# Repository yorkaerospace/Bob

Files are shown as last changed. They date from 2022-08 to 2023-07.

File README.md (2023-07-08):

# ARCHIVED REPO
Keeping hardware and software in the same repository causes headache on top of headache. To that end, this repo was archived on 2023-07-08 and further development will continue in the following repos:
- [ProtonNumber/Bob-Firmware](https://github.com/ProtonNumber/Bob-Firmware)  
- [ProtonNumber/Bob-Hardware](https://github.com/ProtonNumber/Bob-Hardware)
- [ProtonNumber/Bob-Drivers](https://github.com/ProtonNumber/Bob-Drivers)

# Bob

Simple RP2040 based datalogger.

## Rev 3 Specs:

 - 8MB of flash storage (Winbond W25Q64)
 - Barometer/Altimiter (HopeRF HP203B)
 - 6-Axis IMU (QST QMI8658C)
 - 3-Axis Magnetometer (QST QMC5883L)
 
 See docs folder for datasheets.

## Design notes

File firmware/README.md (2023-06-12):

# Bob Firmware
Rewrite of Bob's firmware, using platformIO. The main goal here is to make something simpler, which will hopefully be more reliable and easier to extend.

## Known issues with the old firmware:
 - Overuse of single use function calls.
 - Firmware was split into too many modules, which, combined with the single use functions, made it hard to keep track of program flow.
 - Design was generally bad. It included a lot of functions and states for features that would be implemented "eventually".
 - Used both cores. While in theory this allowed it to sample and log concurrently, in practice you can only write to flash while the other core sleeps.
 - The flash write code is pretty grim.

## Design of the new firmware:
 - Write individual samples to flash; flash writes are *way* faster than initially anticipated, so it may be possible to get away with this. It'd nicely sidestep all the issues we've been having with the flash buffer. The problem is that to do this nicely we effectively need to write 2 pages at once. Not sure what the speed hit from this will be, but I'm willing to take a lower sample rate if we actually get data.
 - Use one core; I am clearly not a good enough programmer to effectively use both. This'll also simplify any write buffer code, if we need it.
 - State machine has been reworked:
   - LOG: Logs data while unplugged.
   - DEBUG_LOG: Logs data while plugged in.
   - DEBUG_PRINT: Prints live data to console. Looks cool, but I'm a bit iffy on this one.
   - DATA_OUT: Prints recorded data as CSV.
   - PLUGGED_IN: Listens to commands over USB.
<p align="center">
  
</p>
 - More states may be added once we actually get some flight data.
 - State machine has been moved into main. This makes main() a bit big but I'm not sure how else to do it.

## Usage

You need to install [`wizio-pico`](https://github.com/Wiz-IO/wizio-pico) to build the firmware.

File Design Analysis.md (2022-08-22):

# Bob Rev 1 (Not built)
 - JLC PCB accepts revisions if you contact customer support *quickly*.
 - Ensure breakout pins are aligned to a 0.1" grid.
 - Ensure USB traces are correctly sized to get the correct impedance.
 	- This involves a lot of maths. Use [a calculator.](https://www.pcbway.com/pcb_prototype/impedance_calculator.html)
# Bob Rev 2
 - Screw switch has large thermal mass, so it needs to be soldered first.
 	 - It is also large, so the nut should be located *far* away from other components so you can actually solder them.
 	 - Eggtimer uses a brass nut, but I was able to get it to work with random M3s I found lying around.
 		 - Chromed or galved nuts *don't* work.
 	 - Needs to have some form of shake-prevention, e.g. nylock or shakeproof washer.
 	 - JLC fills hole with copper, which needs to be filed out.
 	 - M2 is probably more reasonable. 
 	 - Aside from this, seems to work well as a detail.
 - 0603's are the absolute smallest that can be soldered with "normal" soldering supplies.
 	 - 0806 is probably more reasonable.
 	 - 0402 is *pain*.
 - Hot air and flux make everything *so much* easier.
 	 - Fluid tension pulls components into alignment in a *very* satisfying way.
 	 - Flux doesn't hold QFNs that well, but heating the board and dropping the package on seems to work.
 	 - Leaving flux on the board too long can tarnish the pads. 
 	 	 - May affect reliability.
 	 	 - Is ugly as sin.
 	 	 - Pads can still be tinned, but the easiest solution is to *not let it happen*.
 	 	 - Clean board with IPA and and old toothbrush.
 	 - 0402s have a nasty tendency to tombstone.
 - 5032 crystals are hard to find. 
 - Placing tight arrays of components is difficult.
 - JLC have an assembly option.
# Bob Rev 3
 - LED does not need to be nearly that bright. Use a 220R current limiter.
 - Buy the *right* size of component, you moron.
 - 0.5 mm text is too small, 0.75-1 is probably more reasonable
 - Thermal relief will make soldering things to GND so much easier.
 - Buzzer is not very loud, maybe run it off VBAT?
 - Its perfectly safe to use a button on BOOTSEL.

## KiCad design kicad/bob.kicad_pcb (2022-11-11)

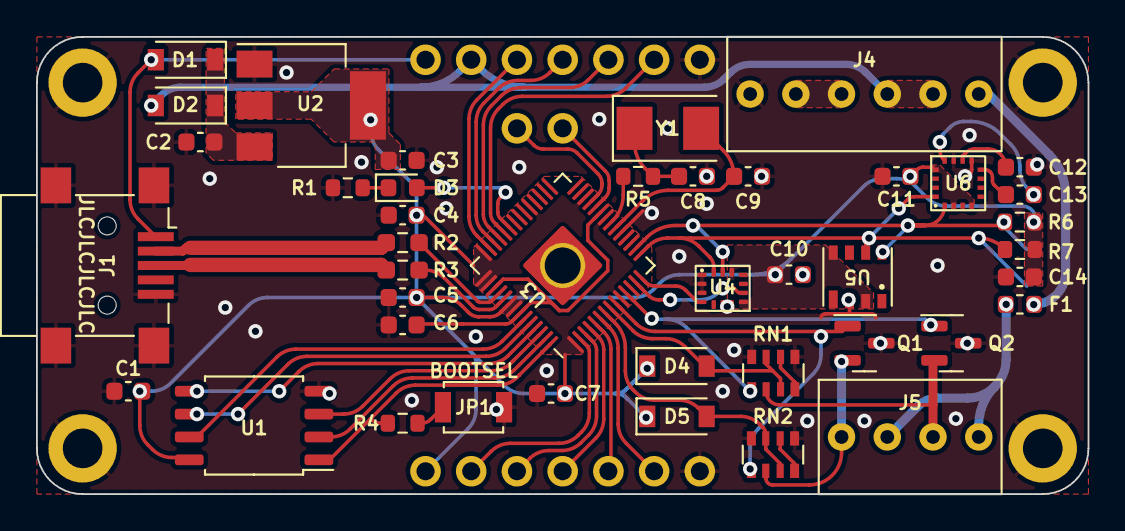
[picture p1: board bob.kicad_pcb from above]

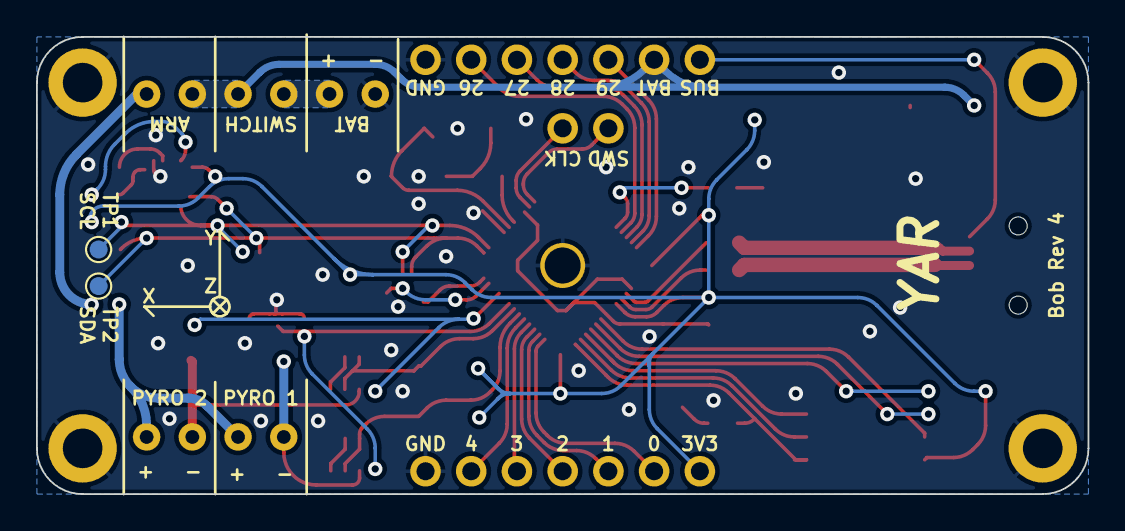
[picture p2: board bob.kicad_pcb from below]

Board: 2 copper layers, 58.4 x 25.4 mm, 52 parts (4 on the bottom side), 51 nets.

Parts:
C1, C5, C7, C10, C11, C14: 100n; C_0603_1608Metric
C2, C3: 10u; C_0603_1608Metric
C4, C6: 1u; C_0603_1608Metric
C8, C9: 4p; C_0603_1608Metric
C12: 4.7u; C_0603_1608Metric
C13: 220n; C_0603_1608Metric
D1, D2, D4, D5: 1N4007; D_SOD-123
D3: RED; LED_0603_1608Metric
F1: Polyfuse; Fuse_0603_1608Metric
H1, H2, H3, H4: MountingHole_Pad; MountingHole_2.2mm_M2_DIN965_Pad
J1: Mini USB Female; USB_Mini-B_Lumberg_2486_01_Horizontal
J2, J3: GPIO (Optional); PinHeader_1x07_P2.54mm_Vertical_NoSilk
J4: Screw Terminal, 2.54mm; ScrewTerm_2.54x06
J5: Conn_01x04_Male; ScrewTerm_2.54x04
J6: Conn_01x03_Male; PinHeader_1x02_P2.54mm_Vertical
JP1: BOOTSEL; SW_SPST_B3U-1000P
Q1, Q2: IRFML8244TRPBF; SOT-23
R1: 220; R_0603_1608Metric
R2, R3: 27; R_0603_1608Metric_Pad0.98x0.95mm_HandSolder
R4, R5: 1k; R_0603_1608Metric
R6, R7: 10k; R_0603_1608Metric
RN1, RN2: 22k; R_Array_Convex_4x0603
TP1, TP2: TestPoint; TestPoint_Pad_D1.0mm
U1: W25Q64JVSS; SOIC-8_5.23x5.23mm_P1.27mm
U2: AMS1117-3.3; SOT-223-3_TabPin2
U3: RP2040; RP2040-QFN-56_HS
U4: QMI8658C; QMI8658C-LGA14
U5: HP203B; HP203B-LGA8
U6: QMC5883L; QMC5883L-LGA16
Y1: 12MHz; Crystal_SMD_5032-2Pin_5.0x3.2mm
YAR: LOGO; YAR_Logo

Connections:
+1V1: C6.1, U3.23 (DVDD), U3.45 (VREG_VOUT), U3.50 (DVDD)
+3V3: C1.1, C3.1, C4.1, C5.1, C7.1, C10.1, C11.1, C14.1, D4.1 (K), D5.1 (K), J3.1, R6.2, R7.2, U1.8 (VCC), U2.2 (VO), U3.1 (IOVDD), U3.10 (IOVDD), U3.22 (IOVDD), U3.26 (RUN), U3.33 (IOVDD), U3.42 (IOVDD), U3.43 (ADC_AVDD), U3.44 (VREG_IN), U3.48 (USB_VDD), U3.49 (IOVDD), U4.8 (VDD), U4.12 (CS), U5.3 (VDD), U5.8 (CSB), U6.2 (VDD), U6.4 (S1), U6.13 (VIO)
+BATT: D2.2 (A), J2.2, J4.4, J4.5
ARM: F1.2, J5.2, J5.4
Cont 1: D5.2 (A), RN2.3 (R3.1), RN2.7 (R2.2), U3.7 (GPIO5)
Cont 2: D4.2 (A), RN1.3 (R3.1), RN1.7 (R2.2), U3.8 (GPIO6)
Fire 1: J5.1, Q1.2 (D), RN2.2 (R2.1)
Fire 2: J5.3, Q2.2 (D), RN1.2 (R2.1)
GND: C1.2, C2.2, C3.2, C4.2, C5.2, C6.2, C7.2, C8.1, C9.1, C10.2, C11.2, C12.1, C14.2, H1.1, H2.1, H3.1, H4.1, J1.5 (GND), J1.6 (Shield), J2.7, J3.7, J4.1, JP1.1 (A), Q1.3 (S), Q2.3 (S), R1.2, RN1.5 (R4.2), RN1.8 (R1.2), RN2.5 (R4.2), RN2.8 (R1.2), U1.4 (GND), U2.1 (GND), U3.19 (TESTEN), U3.57 (GND), U4.1 (SDO/SA0), U4.2 (SDX), U4.3 (SCX), U4.6 (GND), U4.7 (GND), U5.2 (GND), U6.9 (GND), U6.11 (GND)
GPIO0: J3.2, U3.2 (GPIO0)
GPIO1: J3.3, U3.3 (GPIO1)
GPIO2: J3.4, U3.4 (GPIO2)
GPIO3: J3.5, U3.5 (GPIO3)
GPIO4: J3.6, U3.6 (GPIO4)
GPIO26: J2.6, U3.38 (GPIO26_ADC0)
GPIO27: J2.5, U3.39 (GPIO27_ADC1)
GPIO28: J2.4, U3.40 (GPIO28_ADC2)
GPIO29: J2.3, U3.41 (GPIO29_ADC3)
I2C_SCL: R6.1, TP1.1, U3.16 (GPIO13), U4.13 (SCL), U5.5 (SCL), U6.1 (SCL)
I2C_SDA: R7.1, TP2.1, U3.15 (GPIO12), U4.14 (SDA), U5.6 (SDA), U6.16 (SDA)
unnamed: C2.1, D1.1 (K), D2.1 (K), U2.3 (VI)
unnamed: C8.2, R5.1, Y1.1
unnamed: C12.2, U6.10 (C1)
unnamed: C13.1, U6.8 (SETP)
unnamed: C13.2, U6.12 (SETC)
unnamed: D3.1 (K), R1.1
unnamed: D3.2 (A), U3.37 (GPIO25)
unnamed: F1.1, J4.6
unnamed: J4.2, J4.3
unnamed: JP1.2 (B), R4.1
unnamed: R3.1, U3.47 (USB_DP)
unnamed: R2.1, U3.46 (USB_DM)
unnamed: RN2.4 (R4.1), RN2.6 (R3.2)
unnamed: RN1.4 (R4.1), RN1.6 (R3.2)
Pyro 1: Q1.1 (G), RN2.1 (R1.1), U3.9 (GPIO7)
Pyro 2: Q2.1 (G), RN1.1 (R1.1), U3.11 (GPIO8)
QMI_INT1: U3.14 (GPIO11), U4.4 (INT1)
QMI_INT2: U3.13 (GPIO10), U4.9 (INT2)
QSPI_SCLK: U1.6 (CLK), U3.52 (QSPI_SCLK)
QSPI_SD0: U1.5 (DI(IO0)), U3.53 (QSPI_SD0)
QSPI_SD1: U1.2 (DO(IO1)), U3.55 (QSPI_SD1)
QSPI_SD2: U1.3 (IO2), U3.54 (QSPI_SD2)
QSPI_SD3: U1.7 (IO3), U3.51 (QSPI_SD3)
QSPI_SS: R4.2, U1.1 (~CS), U3.56 (QSPI_SS)
SWCLK: J6.2, U3.24 (SWCLK)
SWD: J6.1, U3.25 (SWD)
USB_D+: J1.3 (D+), R3.2
USB_D-: J1.2 (D-), R2.2
VBUS: D1.2 (A), J1.1 (VBUS), J2.1
XIN: C9.2, U3.20 (XIN), Y1.2
XOUT: R5.2, U3.21 (XOUT)

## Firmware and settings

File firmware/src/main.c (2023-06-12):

#include "stdio.h"

#include "pico/stdlib.h"
#include "hardware/i2c.h"
#include "hardware/irq.h"
#include "pico/multicore.h"
#include "pico/bootrom.h"

#include "ansi.h"
#include "sampler.h"

enum states {
    PLUGGED_IN,  // Connected to USB
    DATA_OUT,    // Printing flight data to USB
    DEBUG_PRINT, // Printing debug data to USB
    DEBUG_LOG,   // Logging data while plugged in
    LOG          // Logging data while unplugged
};

enum states state = PLUGGED_IN;
uint32_t readIndex = 0;

void cmdInterpreter(void);

sample_t sampleAndLog(uint8_t freq);

int main() {
    sample_t sample;

    stdio_init_all();
    configureSensors();

    while (true) {
        switch (state) {
        case PLUGGED_IN:
            // State transition logic
            state = stdio_usb_connected() ? PLUGGED_IN : LOG;
            printf(SHOWC);
            cmdInterpreter();
            break;
        case LOG:
            state = stdio_usb_connected() ? PLUGGED_IN : LOG;

            sampleAndLog(100);

            break;
        case DEBUG_PRINT:
            // If unplugged, go to LOG
            state = stdio_usb_connected() ? DEBUG_PRINT : LOG;
            // Return to PLUGGED_IN if the user presses a key
            state = getchar_timeout_us(0) == PICO_ERROR_TIMEOUT ? DEBUG_PRINT : PLUGGED_IN;

            sample = getSample();
            prettyPrint(sample, "Press any key to exit");
            sleep_ms(100);

            break;
        case DEBUG_LOG:
            // If unplugged, go to LOG
            state = stdio_usb_connected() ? DEBUG_LOG : LOG;
            // Return to PLUGGED_IN if the user presses a key
            state = getchar_timeout_us(0) == PICO_ERROR_TIMEOUT ? DEBUG_LOG : PLUGGED_IN;

            sample = sampleAndLog(100);
            prettyPrint(sample, "Press any key to stop logging");

            break;
        case DATA_OUT:
            // If unplugged, go to LOG
            state = stdio_usb_connected() ? DEBUG_PRINT : LOG;
            // If we're out of data, go to PLUGGED_IN
            state = readSample(readIndex, &sample) ? PLUGGED_IN : DATA_OUT;

            printf("%u, %d, %u, %d, %d, %d, %d, %d, %d, %d, %d, %d, %d\n",
                   sample.time, sample.status, sample.pres, sample.temp,
                   sample.mag[0], sample.mag[1], sample.mag[2],
                   sample.accel[0], sample.accel[1], sample.accel[2],
                   sample.gyro[0], sample.gyro[1], sample.gyro[2]);

            readIndex++;
            break;
        }
    }
}

/* Takes and logs a sample, sleeps to ensure samples are taken at the desired
 * frequency. Returns the logged sample for processing if needed. */
sample_t sampleAndLog(uint8_t freq) {
    sample_t sample;
    absolute_time_t nextPoll;

    nextPoll = make_timeout_time_ms(1000/freq);
    sample = getSample();
    logSample(sample);
    sleep_until(nextPoll);

    return sample;
}

/* Interprets and executes commands being given over STDIN */
void cmdInterpreter(void) {

    static const char helpText[] =
        "Bob Rev 3 running build: %s %s\n"
        "Press:\n"
        "b to enter bootsel mode\n"
        "c to clear the contents of the flash\n"
        "d to show the debug prompt\n"
        "h to display this help text\n"
        "l to start manual logging\n"
        "r to read files\n";

    // Interpret commands
    switch(getchar_timeout_us(0)) {
    case PICO_ERROR_TIMEOUT:         // If there is no char, just break.
        break;
    case 'd':
        printf(HIDEC);
        state = DEBUG_PRINT;
        break;
    case 'l':
        printf(HIDEC);
        state = DEBUG_LOG;
        break;
    case 'r':
        readIndex = 0;
        state = DATA_OUT;
        break;
    case 'c':
        printf(NORM
               "Are you sure you wish to clear the flash? "
               "["GREEN "Y" WHITE "/" RED "N" WHITE "]\n"
               NORM);
        switch(getchar_timeout_us(30000000)){
        case PICO_ERROR_TIMEOUT:
            printf("Timed out due to lack of response, please try again\n");
            break;
        case 'y':
            printf("Clearing flash. (This may take a while) \n");
            clearFlash();
            printf("Done!\n");
            break;
        }
        break;
    case 'b':
        printf("Entering bootsel mode...\n");
        reset_usb_boot(0,0);
        break;
    case 'h':
        printf(helpText, __TIME__, __DATE__);
        break;
    default:
        printf("Invalid command. Press h for help.\n");
        break;
    }
}

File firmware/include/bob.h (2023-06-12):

/*  Header file containing bob-specific constants
    This overrides a lot of things that the SDK sets by default
    You dont have to include this in any code you write; the SDK
    should include it by default. */
#ifndef BOB_H
#define BOB_H

// For board detection
#define YAR_BOB

// Internal I2C bus
#ifndef PICO_DEFAULT_I2C
    #define PICO_DEFAULT_I2C 0
#endif

#ifndef PICO_DEFAULT_I2C_SDA_PIN
    #define PICO_DEFAULT_I2C_SDA_PIN 16
#endif

#ifndef PICO_DEFAULT_I2C_SCL_PIN
    #define PICO_DEFAULT_I2C_SCL_PIN 17
#endif

// Size of the flash storage in bytes
#define PICO_BOOT_STAGE2_CHOOSE_W25Q080 1

#ifndef PICO_FLASH_SPI_CLKDIV
    #define PICO_FLASH_SPI_CLKDIV 2
#endif

#ifndef PICO_FLASH_SIZE_BYTES
#define PICO_FLASH_SIZE_BYTES (8 * 1024 * 1024)
#endif


// Buzzer
#define BOB_BUZZER 7

#endif

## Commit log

2022-07-04 Add kicad files
    [bob-B_Cu.gbr, bob-B_Mask.gbr, bob-B_Paste.gbr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]
2022-07-04 Removed gbr files, fixed gitignore
    [bob-B_Cu.gbr, bob-B_Mask.gbr, bob-B_Paste.gbr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]
2022-07-04 Rearranged directories
    [bob.kicad_pcb, bob.kicad_sch]
2022-07-04 Fixed issues with USB impedance
    [bob.kicad_pcb]
2022-07-11 Created a simple BMP driver, and some helper thingys.
2022-07-21 Added notes from assembling PCB
2022-07-24 Fixed MPU6050 charge pump cap
    [bob.kicad_sch]
2022-07-24 Replaced BMP180 with HP203B
    [bob.kicad_sch]
2022-07-24 Added piezo buzzer
    [bob.kicad_sch]
2022-07-24 Moved I2C to bottom of RP2040
    [bob.kicad_sch]
2022-07-24 Changed 0402s to 0603s
    [bob.kicad_sch]
2022-07-24 Added SWD connector and test points
    [bob.kicad_sch]
2022-07-24 Broke out VBAT
    [bob.kicad_sch]
2022-07-25 Added a magnetometer
    [bob.kicad_sch]
2022-07-28 Rev 3, issued for production
    [bob.kicad_pcb, bob.kicad_sch]
2022-07-28 Added addresses to I2C bus
    [bob.kicad_sch]
2022-07-28 Fixed issues and reissued for production
    [bob.kicad_pcb]
2022-08-22 Added address for QMC5883L
    [bob.kicad_sch]
2022-08-22 Added Kicad Libs. Added thermal relief.
    [bob.kicad_pcb]
2022-08-22 Added nice symbols to schematic
    [bob.kicad_sch]
2022-08-22 Changed LED current limiter so it wont be so bright
    [bob.kicad_sch]
2022-08-22 Changed SW1 to a button
    [bob.kicad_sch]
2022-08-22 Nope, switch wont fit :(
    [bob.kicad_sch]
2022-08-22 Updated footprints to be much saner
    [bob.kicad_sch]
2022-08-22 Changed U3 to the new symbol libs
    [bob.kicad_sch]
2022-08-23 Started on a HP203B driver
2022-09-07 Fixed very minor alignment issue that was annoying me.
    [bob.kicad_sch]
2022-09-10 Started work on a magnetometer driver
2022-09-12 Added more formal board support.
2022-09-17 Removed pico SDK and recursive deps
2022-09-18 Moved sensors into their own libs
2022-09-19 Fixed the awful crash bug that drove me insane
    [main.c]
2022-09-21 QMIReadBytes now reads the correct number of bytes
    [main.c]
2022-09-22 Fixed bug in QMISetOption
    [main.c]
2022-09-24 Magnetometer data is now just put in an array
2022-09-25 Removed stray printf
2022-09-25 Created module to manage and poll sensors as a unit
2022-09-25 Increased I2C baudrate
2022-09-25 Moved sensor handling onto core 1
2022-09-26 Created a statemachine to manage program flow
2022-10-20 Moved stateDetect to sensors.c for easier testing
2022-11-05 Fixed a weird crash by waiting
    [main.c]
2022-11-08 Added pyro channels Added bendy traces Added status LED Removed buzzer
    [Pyro.kicad_sch, bob.kicad_pcb, bob.kicad_sch]
2022-11-11 Started work on bob R4
    [bob.kicad_pcb]
2022-11-22 Added platformIO config file and somewhat cleaned sensor libs
2022-11-28 Corrected memory miscalculation and added the documentation
    [bob.h]
2023-03-05 refactor: tighten up readData script
2023-03-12 Copy old sensor init code
2023-03-12 Sneaky missing semicolon <_<
    [main.c]
2023-03-13 Fleshed out sampler
2023-03-13 Fixed some syntax errors caused by careless copying
    [sampler.c]
2023-03-13 Fixed some include issues, and some embarassing syntax errors
    [sampler.c]
2023-03-13 Fixed more careless copying
    [main.c, sampler.c]
2023-03-14 Added interrupt guards to logSample
2023-03-14 Added PrettyPrint to replace the old debug print
    [main.c, sampler.c]
2023-03-14 Display flash used in kiB. Avoids horrifying double cast
    [sampler.c]
2023-03-14 Fixed flash not writing. Forgot that writePtr was not a flash address, but a memory address.
    [sampler.c]
2023-03-14 Added the timestamp to samples
2023-03-15 doc: add wizio-pico note to firmware
2023-03-16 Added interrupt guards to clearFlash
2023-03-17 Increased sample rate
2023-03-17 Created SampleAndLog to simplify main slightly
2023-03-17 Replaced stupid ? with an actually useful error message
    [main.c]
2023-03-17 Fix bug in HP203 Error handling
    [sampler.c]
2023-03-17 Create macros for GYRO_RANGE and ACCL_RANGE
2023-03-17 DEBUG_PRINT No longer writes data to flash
    [main.c]
2023-03-18 Fixed issues found by pio check.
    [main.c, sampler.c]
